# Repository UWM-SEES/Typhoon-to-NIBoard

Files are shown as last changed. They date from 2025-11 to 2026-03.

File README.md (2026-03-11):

# Typhoon to National Instruments Interface Board

## Overview
This interface board was designed to connect Typhoon HIL hardware to National Instruments PXIe-7862 FPGA cards. It provides a hardware interface between Typhoon HIL systems using DIN41612 3×32 connectors and the NI SHC68-68-RMIO cable used by the PXIe-7862.

The board uses the connector spacing from the Typhoon HIL Breakout Board R3.3, which is available from the Typhoon HIL website.

The interface allows signals from the Typhoon HIL system to be routed to one or two NI PXIe-7862 cards.

---

## Hardware Compatibility

### Typhoon HIL
Any Typhoon HIL system supporting:
- Two DIN41612 3×32 connectors

### National Instruments
- PXIe-7862 FPGA cards
- SHC68-68-RMIO cables

---

## Multi-Card Support

The PXIe-7862 connector has a limited number of analog output channels.

Because of this:

- The interface board can operate with **one PXIe-7862 card**
- It can also connect to **two PXIe-7862 cards**

When using two cards, additional analog outputs become available.

When using only one card, the analog outputs routed to the second connector will not be used.

---

## Analog Signal Behavior

Typhoon HIL outputs **single-ended analog signals**, not differential signals.

Therefore:

- The PXIe-7862 **analog input (+)** receives the signal.
- The **analog input (-)** is **not connected** on this interface board.

---

## Grounding

Typhoon HIL uses shared grounds rather than per-channel grounds.

### Analog
All analog channels share **one analog ground**

### Digital
All digital channels share **one digital ground**

### Important
Analog ground and digital ground are **separate from each other**.

---

## Digital I/O Configuration

Typhoon and NI handle digital signals differently.

### Typhoon
Digital inputs and outputs are on **separate pins**.

### PXIe-7862
Digital pins are **configurable as either input or output**.

---

## Direction Selection Switches

To support this difference, the interface board includes switches that select the signal direction.

Each digital channel can be configured for:

- **NI Input (Typhoon Output)**
- **NI Output (Typhoon Input)**

If you want:

- NI to read a signal → set the switch to **NI Input / Typhoon Output**
- NI to drive a signal → set the switch to **NI Output / Typhoon Input**

All switches are labeled directly on the PCB and referenced in the pinout diagram.

---

## Pinout Diagram

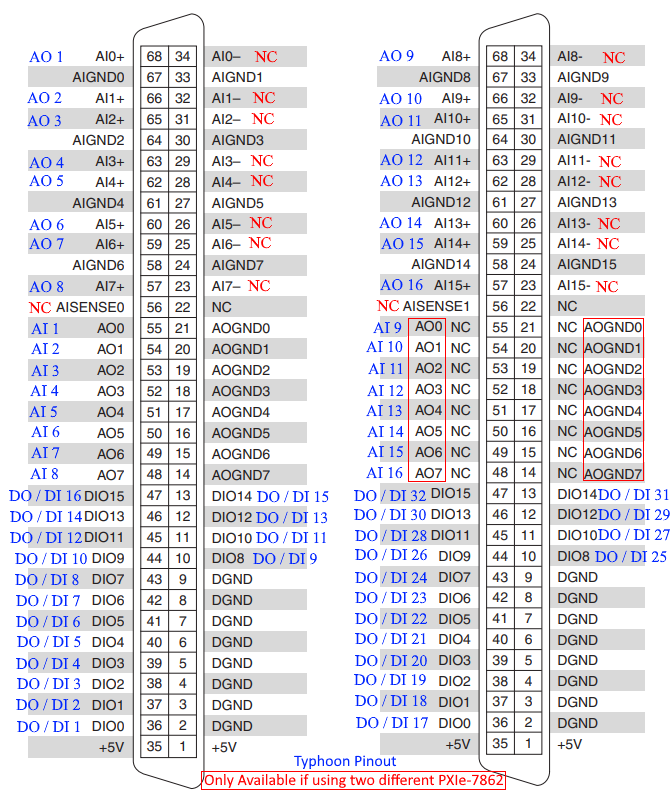
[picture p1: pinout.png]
Typhoon Pinout


---

## Notes

- Analog inputs are single-ended.
- Analog negative pins on the NI side are unused.
- Digital signals require direction selection via switches.
- Two NI cards can be used to increase available analog outputs.

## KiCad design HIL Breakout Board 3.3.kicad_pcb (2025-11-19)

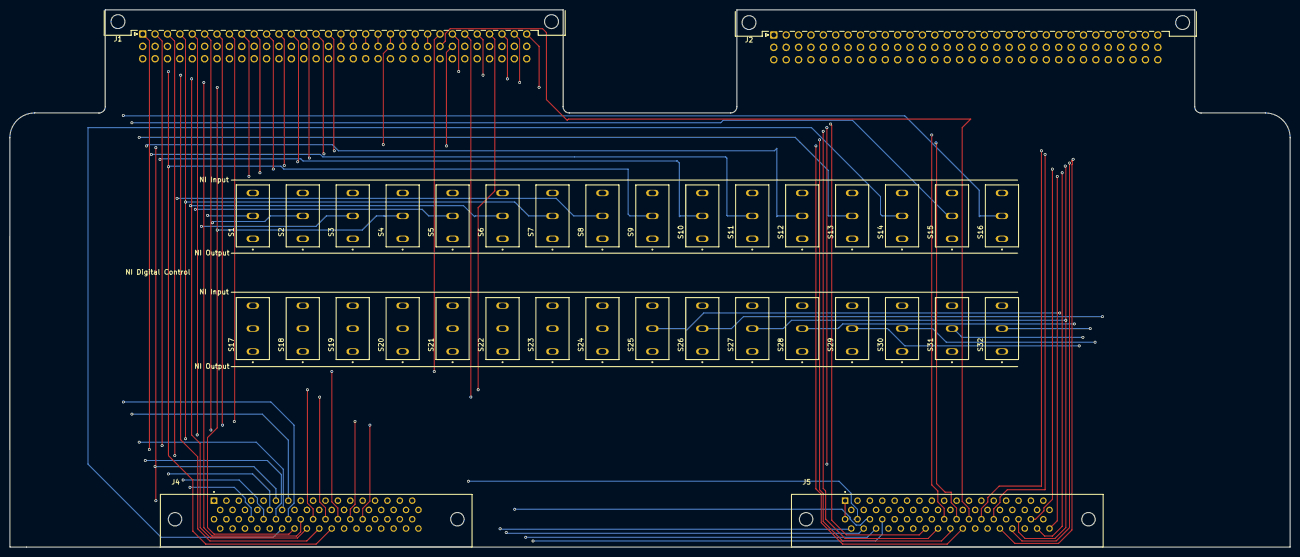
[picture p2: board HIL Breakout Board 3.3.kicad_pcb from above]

Board: 6 copper layers, 262.5 x 110.1 mm, 36 parts (0 on the bottom side), 137 nets.

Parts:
J1, J2: DIN41612_03x32_C_Split; DIN41612_R_3x32_Female_Horizontal_THT
J4, J5: 2-5174225-5; TE_2-5174225-5
S1, S2, S3, S4, S5, S6, S7, S8, S9, S10, S11, S12, S13, S14, S15, S16, S17, S18, S19, S20, S21, S22, S23, S24, S25, S26, S27, S28, S29, S30, S31, S32: SLW-1276864-4A-D; SW_SLW-1276864-4A-D

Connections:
3.3VDout: J2.c4, J2.c5
3.3VDout_1: J2.c1, J2.c2, J2.c3
5VDout: J2.c28, J2.c29, J2.c30
+5Vout: J1.a21, J1.a22, J1.b21, J1.b22, J4.A1, J4.B1, J5.A1, J5.B1
+12Vout: J1.a17, J1.a18, J1.b17, J1.b18
-5Vout: J1.a23, J1.a24, J1.b23, J1.b24
-12Vout: J1.a19, J1.a20, J1.b19, J1.b20
AGND: J1.c1, J1.c2, J1.c3, J1.c4, J1.c5, J1.c6, J1.c7, J1.c8, J1.c9, J1.c10, J1.c11, J1.c12, J1.c13, J1.c14, J1.c15, J1.c16, J1.c17, J1.c18, J1.c19, J1.c20, J1.c21, J1.c22, J1.c23, J1.c24, J1.c25, J1.c26, J1.c27, J1.c28, J1.c29, J1.c30, J1.c31, J1.c32, J4.A14, J4.A15, J4.A16, J4.A17, J4.A18, J4.A19, J4.A20, J4.A21, J4.A24, J4.A27, J4.A30, J4.A33, J4.B24, J4.B27, J4.B30, J4.B33, J5.A14, J5.A15, J5.A16, J5.A17, J5.A18, J5.A19, J5.A20, J5.A21, J5.A24, J5.A27, J5.A30, J5.A33, J5.B24, J5.B27, J5.B30, J5.B33
AI0: J1.a25, J4.B21
AI1: J1.a26, J4.B20
AI2: J1.a27, J4.B19
AI3: J1.a28, J4.B18
AI4: J1.a29, J4.B17
AI5: J1.a30, J4.B16
AI6: J1.a31, J4.B15
AI7: J1.a32, J4.B14
AI8: J1.b25, J5.B21
AI9: J1.b26, J5.B20
AI10: J1.b27, J5.B19
AI11: J1.b28, J5.B18
AI12: J1.b29, J5.B17
AI13: J1.b30, J5.B16
AI14: J1.b31, J5.B15
AI15: J1.b32, J5.B14
AO0: J1.a1, J4.B34
AO1: J1.a2, J4.B32
AO2: J1.a3, J4.B31
AO3: J1.a4, J4.B29
AO4: J1.a5, J4.B28
AO5: J1.a6, J4.B26
AO6: J1.a7, J4.B25
AO7: J1.a8, J4.B23
AO8: J1.a9, J5.B34
AO9: J1.a10, J5.B32
AO10: J1.a11, J5.B31
AO11: J1.a12, J5.B29
AO12: J1.a13, J5.B28
AO13: J1.a14, J5.B26
AO14: J1.a15, J5.B25
AO15: J1.a16, J5.B23
DGND: J2.c6, J2.c7, J2.c8, J2.c9, J2.c10, J2.c11, J2.c12, J2.c13, J2.c14, J2.c15, J2.c16, J2.c17, J2.c18, J2.c19, J2.c20, J2.c21, J2.c22, J2.c23, J2.c24, J2.c25, J2.c26, J2.c27, J4.A2, J4.A3, J4.A4, J4.A5, J4.A6, J4.A7, J4.A8, J4.A9, J5.A2, J5.A3, J5.A4, J5.A5, J5.A6, J5.A7, J5.A8, J5.A9
DI0: J2.a1, S1.1
DI1: J2.a2, S2.1
DI2: J2.a3, S3.1
DI3: J2.a4, S4.1
DI4: J2.a5, S5.1
DI5: J2.a6, S6.1
DI6: J2.a7, S7.1
DI7: J2.a8, S8.1
DI8: J2.a9, S9.1
DI9: J2.a10, S10.1
DI10: J2.a11, S11.1
DI11: J2.a12, S12.1
DI12: J2.a13, S13.1
DI13: J2.a14, S14.1
DI14: J2.a15, S15.1
DI15: J2.a16, S16.1
DI16: J2.a17, S17.1
DI17: J2.a18, S18.1
DI18: J2.a19, S19.1
DI19: J2.a20, S20.1
DI20: J2.a21, S21.1
DI21: J2.a22, S22.1
DI22: J2.a23, S23.1
DI23: J2.a24, S24.1
DI24: J2.a25, S25.1
DI25: J2.a26, S26.1
DI26: J2.a27, S27.1
DI27: J2.a28, S28.1
DI28: J2.a29, S29.1
DI29: J2.a30, S30.1
DI30: J2.a31, S31.1
DI31: J2.a32, S32.1
DO0: J2.b1, S1.3
DO1: J2.b2, S2.3
DO2: J2.b3, S3.3
DO3: J2.b4, S4.3
DO4: J2.b5, S5.3
DO5: J2.b6, S6.3
DO6: J2.b7, S7.3
DO7: J2.b8, S8.3
DO8: J2.b9, S9.3
DO9: J2.b10, S10.3
DO10: J2.b11, S11.3
DO11: J2.b12, S12.3
DO12: J2.b13, S13.3
DO13: J2.b14, S14.3
DO14: J2.b15, S15.3
DO15: J2.b16, S16.3
DO16: J2.b17, S17.3
DO17: J2.b18, S18.3
DO18: J2.b19, S19.3
DO19: J2.b20, S20.3
DO20: J2.b21, S21.3
DO21: J2.b22, S22.3
DO22: J2.b23, S23.3
DO23: J2.b24, S24.3
DO24: J2.b25, S25.3
DO25: J2.b26, S26.3
DO26: J2.b27, S27.3
DO27: J2.b28, S28.3
DO28: J2.b29, S29.3
DO29: J2.b30, S30.3
DO30: J2.b31, S31.3
DO31: J2.b32, S32.3
unnamed: J4.A10, S9.2
unnamed: J4.A11, S11.2
unnamed: J4.A12, S13.2
unnamed: J4.A13, S15.2
unnamed: J4.B2, S1.2
unnamed: J4.B3, S2.2
unnamed: J4.B4, S3.2
unnamed: J4.B5, S4.2
unnamed: J4.B6, S5.2
unnamed: J4.B7, S6.2
unnamed: J4.B8, S7.2
unnamed: J4.B9, S8.2
unnamed: J4.B10, S10.2
unnamed: J4.B11, S12.2
unnamed: J4.B12, S14.2
unnamed: J4.B13, S16.2
unnamed: J5.A10, S25.2
unnamed: J5.A11, S27.2
unnamed: J5.A12, S29.2
unnamed: J5.A13, S31.2
unnamed: J5.B2, S17.2
unnamed: J5.B3, S18.2
unnamed: J5.B4, S19.2
unnamed: J5.B5, S20.2
unnamed: J5.B6, S21.2
unnamed: J5.B7, S22.2
unnamed: J5.B8, S23.2
unnamed: J5.B9, S24.2
unnamed: J5.B10, S26.2
unnamed: J5.B11, S28.2
unnamed: J5.B12, S30.2
unnamed: J5.B13, S32.2

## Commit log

2025-11-13 Added switches for A side
    [HIL Breakout Board 3.3.kicad_pcb]
2025-11-14 Added all DC inputs and outputs for B side of connector
2025-11-14 Added Digital and Analog Grounds Added AN Outputs into A and B
2025-11-14 Added all analog inputs and outputs to schematic Schematic still missing +5 V on pin 1 and 35 and AISENSE1 on pin 56 for A and B side Updated PCB Design
    [HIL Breakout Board 3.3.kicad_pcb]
2025-11-17 Fixed the issue with naming of net labels so that all digital pins were not tied together
    [HIL Breakout Board 3.3.kicad_pcb]
2025-11-17 Got rid of all names of wires because it was causing issues with global variables Started PCB tracks
    [HIL Breakout Board 3.3.kicad_pcb]
2025-11-19 Added all analog traces Changed NI connection to two separate ports Added footprint folders for switch and NI connector
    [HIL Breakout Board 3.3.kicad_pcb, freerouting.dsn, temp-freerouting.dsn]
2025-11-19 Added traces from all switches to NI connector
    [HIL Breakout Board 3.3.kicad_pcb]
2025-11-19 Added all NI input signals to switches
    [HIL Breakout Board 3.3.kicad_pcb]
2025-11-20 Finished all traces on pcb Added labels for all digital switches with connector A and B
2025-11-20 Rounded edges of board
2025-11-20 Added mounting holes
2025-11-21 Refined traces for analog outputs
2025-11-21 Refined Analog Input Traces
2025-11-21 Spaced out traces between switches so they don't overlap at all
2025-11-24 Refined all traces so there is no overlap on adjacent layers and now sharp corners through a via
2026-03-11 Create README.md
    Created a readme file for how to use the interface board
